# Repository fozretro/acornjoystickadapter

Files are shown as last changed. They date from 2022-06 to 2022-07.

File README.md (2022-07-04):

Joystick Adapter for Acorn Archimedes Computers
===============================================

KiCad project for an Archimedes joystick adapter. Derived from an initial design by **Ian Haylock** that plugs externally into the computers parallel port and enables two Atari style joysticks to be plugged in. Software must be installed on the Archimedes to recognize the adapter, see ``software`` folder. Full details and pictures can be found in this Stardot Forum [thread](https://stardot.org.uk/forums/viewtopic.php?f=16&t=24492). See ``release`` folder for latest version manufcatoring files along with a BOM file.

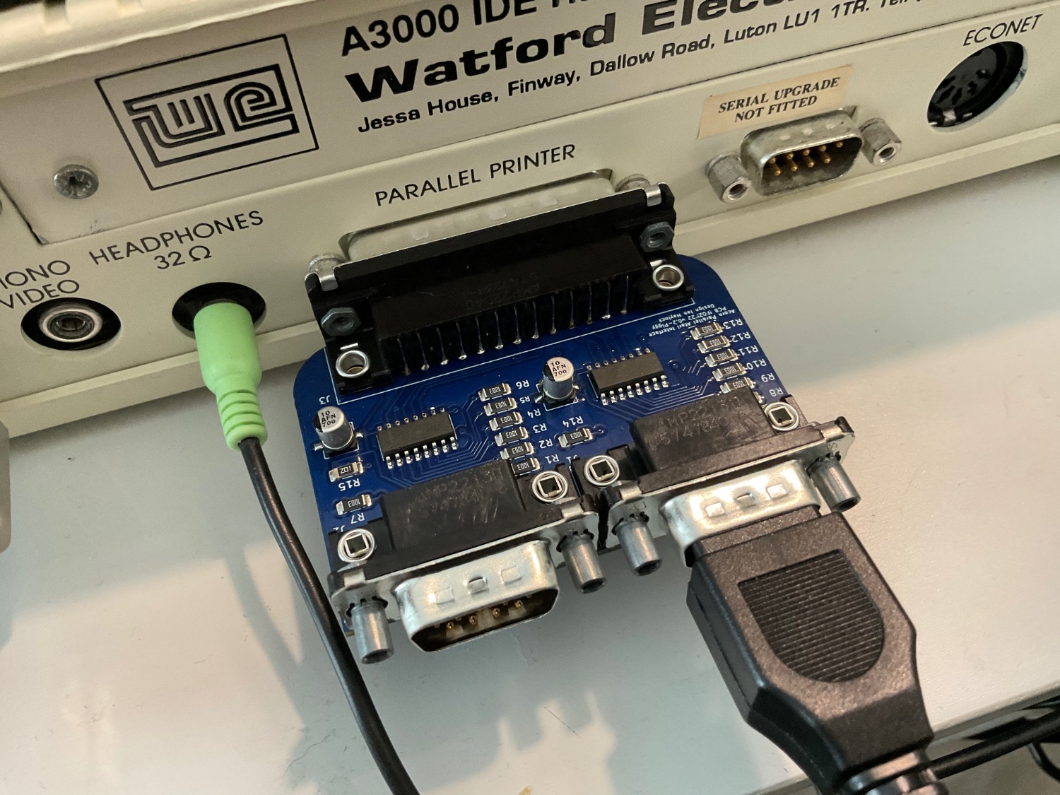
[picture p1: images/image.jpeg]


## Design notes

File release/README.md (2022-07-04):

Release Instructions Notes
==========================

**General editing between releases**

- Currently uses v6.0.4 of KiKad
- Open it to do all editing
- Once done with edits
- Before commiting changes use ***Inspect > Design Rules Checker (DRC)*** and review acceptable warnings

**For each release follow these steps**

- Make sure to update either the schematic version or PCB version (on silkscreen) or both accordingly
- Run the DRC (see above) - make sure no errors and only acceptable warnings
- All files from the follow three steps should update all files in ```/release```
- Run **File > Fabrication Outputs > Generate Gerbers** and select the ```/release``` directory and click Plot
- From the same dialog as above click **Generate Drill Files...**
- Run **File > Fabrication Outputs > Component Placement** click button generate .pos files
- Update ```BOM.csv``` as needed
- Commit changes as normal and create a GitHub Release record

**Current Acceptable Warnings**

- Currently for PCB v.04 there are only 6 warnings relating silkscreen overlap with pads

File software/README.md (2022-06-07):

JoyStick.zip
=============

Orginal **ArcWeld Joystick Adapter** schematic in !Draw format and driver Modules from Ian Haylock. This software and circuit design only seems to exist [here](http://legacy.huber-net.de/Joystick.zip) and is only referenced [here](https://forums.jaspp.org.uk/forum/viewtopic.php?p=3092#p3092). Unzip this on an Acorn Archimedes using apps such as !SparkFS. It is replicated here just in case that site disappears. Source code for the modules has not been found, though it maybe possible to use !ModDis to disassemble. 

**Author:** Ian Haylock

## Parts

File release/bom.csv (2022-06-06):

Item | Ref | Qnty | DigiKey Part # | DigiKey Link | Description | Footprint
1 | C1, C2 | 2 | C_Polarized, 10uf Eletrolitic | https://www.digikey.com/en/products/detail/panasonic-electronic-components/EEE-FN1A100R/11656986 | C_Polarized, 10uf Eletrolitic | Capacitor_SMD:CP_Elec_5x4.4
2 | IC1, IC2 | 2 | DigiKey MC14512BDR2G | https://www.digikey.com/en/products/detail/onsemi/MC14512BDR2G/1478878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 | MC14512BDR2G | MC14512BDR2G:MC14512BDR2G
3 | J1, J2 | 2 | DB9_Male | https://www.digikey.com/en/products/detail/te-connectivity-amp-connectors/5747840-6/808649 | DB9_Male | 5747840-6:5747840-6
4 | J3 | 1 | DB25_Male | https://www.digikey.com/en/products/detail/te-connectivity-amp-connectors/5747238-4/808629 | DB9_Male | 5747238-4:5747238-4
5 | R1, R2, R3, R4, R5, R6, R7, R8, R9, R10, R11, R12, R13, R14 | 14 | 100k | https://www.digikey.com/en/products/detail/panasonic-electronic-components/ERA-8AEB104V/3070743 | 100k | Resistor_SMD:R_1206_3216Metric_Pad1.30x1.75mm_HandSolder
6 | R15 | 1 | 1k | https://www.digikey.com/en/products/detail/panasonic-electronic-components/ERJ-8GEYJ102V/10364 | 1k | Resistor_SMD:R_1206_3216Metric_Pad1.30x1.75mm_HandSolder

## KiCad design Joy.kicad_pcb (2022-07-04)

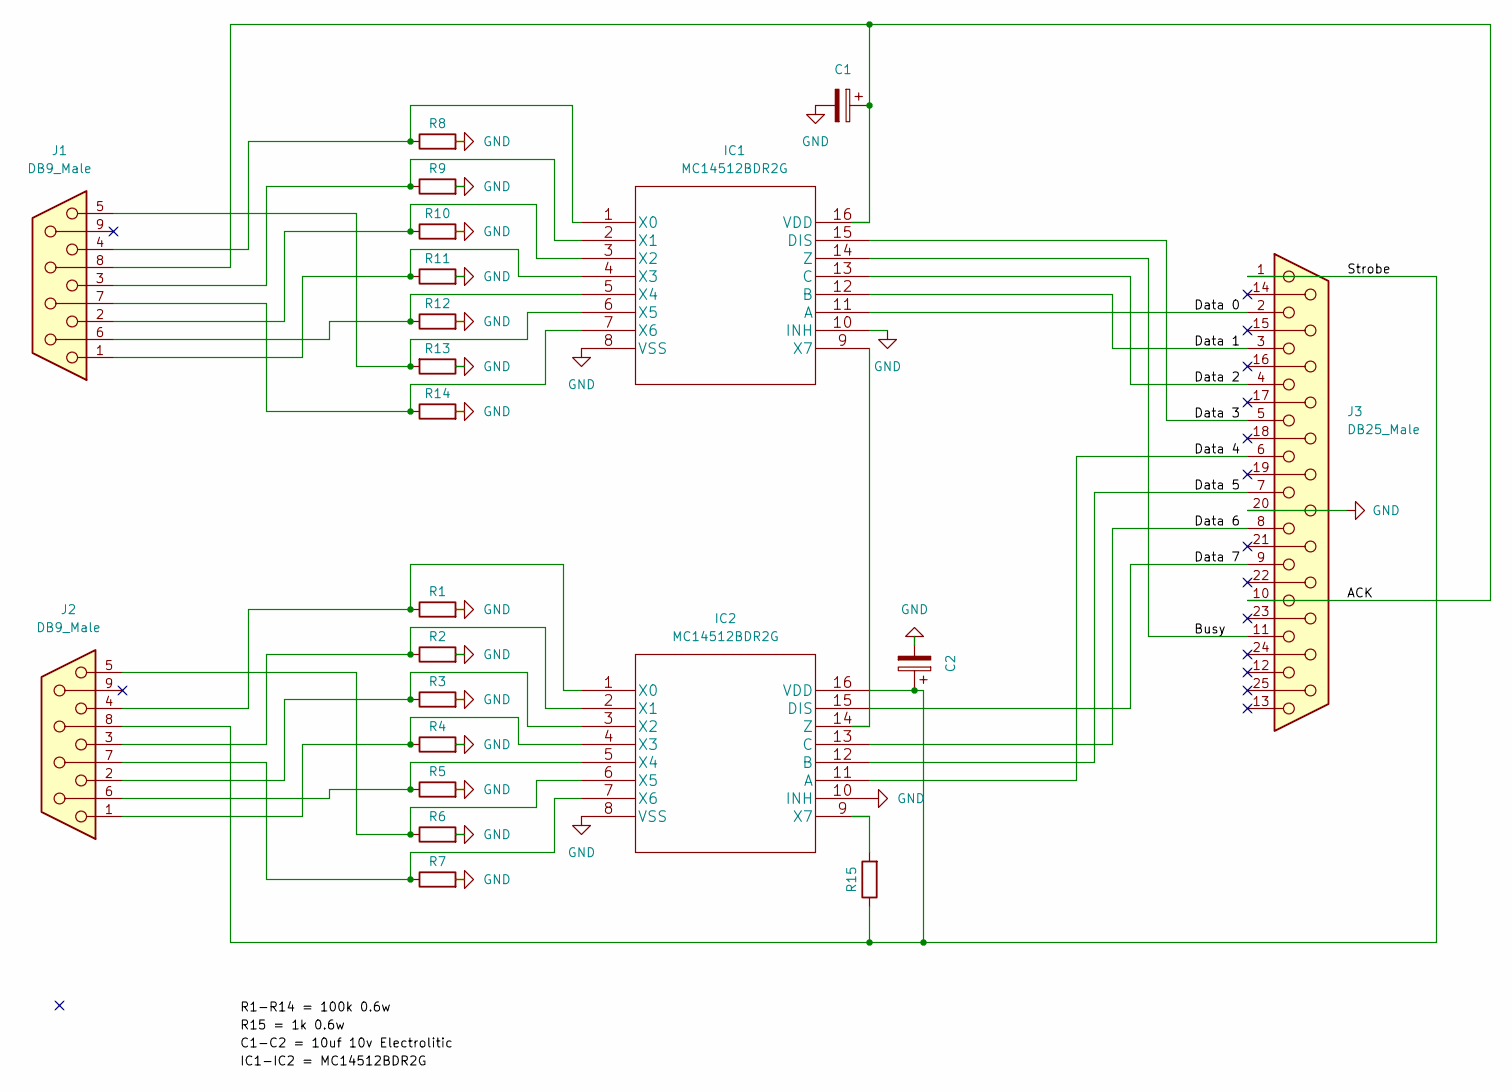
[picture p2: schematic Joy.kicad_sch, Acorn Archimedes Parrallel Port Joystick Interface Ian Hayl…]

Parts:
C1, C2: (no value)
IC1, IC2: MC14512BDR2G
J1, J2: DB9_Male; 5747840-6
J3: DB25_Male; 5747238-4
R1, R2, R3, R4, R5, R6, R7, R8, R9, R10, R11, R12, R13, R14: 100k; R_1206_3216Metric_Pad1.30x1.75mm_HandSolder
R15: 1k; R_1206_3216Metric_Pad1.30x1.75mm_HandSolder

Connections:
/ACK: C1.1, IC1.16 (VDD), J1.8, J3.10
/Busy: IC1.14 (Z), J3.11
/Data 0: IC1.11 (A), J3.2
/Data 1: IC1.12 (B), J3.3
/Data 2: IC1.13 (C), J3.4
/Data 3: IC1.15 (DIS), J3.5
/Data 4: IC2.11 (A), J3.6
/Data 5: IC2.12 (B), J3.7
/Data 6: IC2.13 (C), J3.8
/Data 7: IC2.15 (DIS), J3.9
/Strobe: C2.1, IC2.16 (VDD), J2.8, J3.1, R15.1
GND: C1.2, C2.2, IC1.8 (VSS), IC1.10 (INH), IC2.8 (VSS), IC2.10 (INH), J3.20, R1.2, R2.2, R3.2, R4.2, R5.2, R6.2, R7.2, R8.2, R9.2, R10.2, R11.2, R12.2, R13.1, R14.2
unnamed: IC1.1 (X0), J1.4, R8.1
unnamed: IC1.2 (X1), J1.3, R9.1
unnamed: IC1.3 (X2), J1.2, R10.1
unnamed: IC1.4 (X3), J1.1, R11.1
unnamed: IC1.5 (X4), J1.6, R12.1
unnamed: IC1.6 (X5), J1.5, R13.2
unnamed: IC1.7 (X6), J1.7, R14.1
unnamed: IC1.9 (X7), IC2.14 (Z)
unnamed: IC2.1 (X0), J2.4, R1.1
unnamed: IC2.2 (X1), J2.3, R2.1
unnamed: IC2.3 (X2), J2.2, R3.1
unnamed: IC2.4 (X3), J2.1, R4.1
unnamed: IC2.5 (X4), J2.6, R5.1
unnamed: IC2.6 (X5), J2.5, R6.1
unnamed: IC2.7 (X6), J2.7, R7.1
unnamed: IC2.9 (X7), R15.2

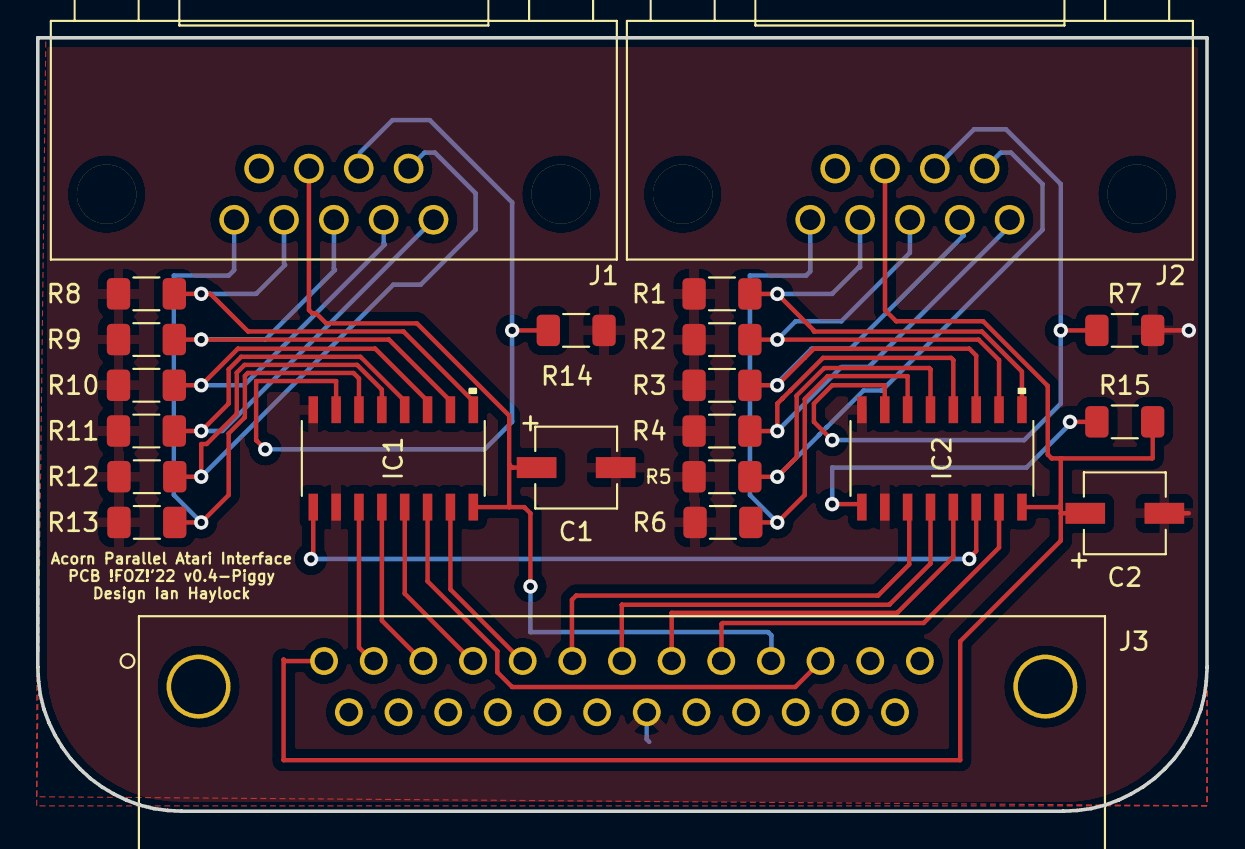
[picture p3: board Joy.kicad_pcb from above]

Board: 2 copper layers, 65.0 x 43.0 mm, 22 parts (0 on the bottom side), 28 nets.

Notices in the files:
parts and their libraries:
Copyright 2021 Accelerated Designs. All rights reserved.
